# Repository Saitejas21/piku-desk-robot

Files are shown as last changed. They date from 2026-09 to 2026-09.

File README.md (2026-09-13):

<div align="center">

# Piku 🐰

**A tiny, sleepy bunny for your desk.**

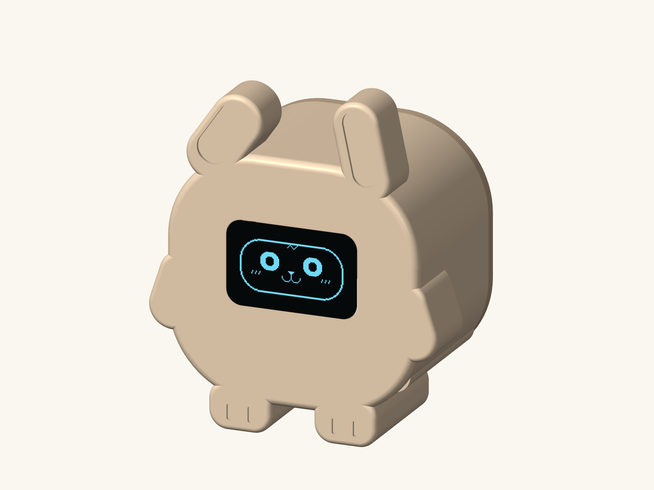
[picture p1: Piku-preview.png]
Piku, a cream bunny desk robot with a tilted ear, tiny paws, and a smiling full face on its OLED screen


USB powered · Touch reactive · About 6.4 cm tall

[Build guide](Piku-build-guide.docx) · [Download the project](https://github.com/Saitejas21/piku-desk-robot/archive/refs/heads/main.zip) · [Print files](cad) · [Push-in mounts](variants/slide-in) · [Otter variant](variants/otter) · [Cat variant](variants/cat)

<sub>CAD preview of the proposed build. The first physical build is still to be tested.</sub>

</div>

Piku is a small ESP32 hobby robot with one tilted ear, little paws, and a whole face on a monochrome OLED: eyes, nose, mouth, and cheeks. Its body stays still while its expressions do the talking.

The build uses **three small boards and two printed parts**. Start with one little win: get Piku's face blinking on the table. Put it in its bunny shell once the electronics work.

## Meet Piku

| What you do | What Piku does |
| --- | --- |
| Let it hang out | Blinks and glances left and right |
| Tap its head | Smiles |
| Double-tap within 450 ms | Shows heart eyes |
| Hold a touch for two seconds | Gives a shy wink |
| Leave it alone for a minute | Falls asleep |
| Touch it while sleeping | Wakes with a surprised face, then smiles |

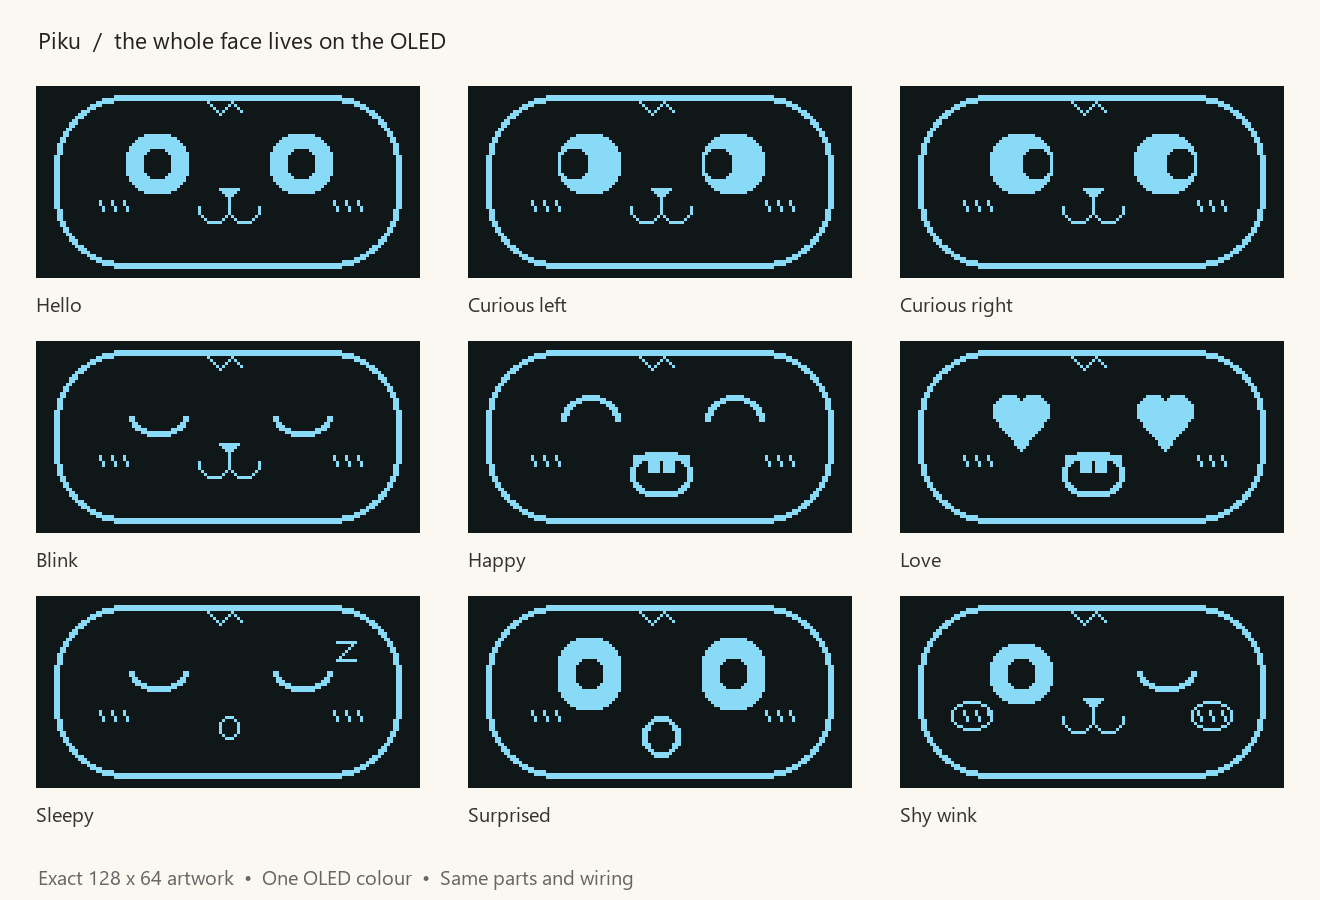
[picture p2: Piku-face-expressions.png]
Piku's nine OLED frames, including happy, love, sleepy, surprised, and a shy wink


These are the actual **128 × 64 pixel frames** included in the sketch. All features use the OLED's single pixel colour; the blue in the preview matches the linked display.

## Gather the little parts

Buy one of each board. **This shell and sketch are designed for the ESP32-C3 SuperMini and SSD1306 display below.**

| Part | What to look for | Buy |
| --- | --- | --- |
| ESP32-C3 SuperMini | HW-466AB, USB-C, with soldered headers | [Quartz Components](https://quartzcomponents.com/collections/nodemcu-esp/products/esp32-c3-super-mini-development-board-with-soldered-headers-hw-466ab) |
| 0.96″ OLED | SSD1306, 128 × 64, **four-pin I²C** | [Quartz Components](https://quartzcomponents.com/products/oled-display-0-96-inch-i2c-interface-4-pin-blue-ssd1306) |
| TTP223 touch sensor | Small **red 15 × 11 mm** board | [DNA Technology](https://www.dnatechindia.com/red-ttp-223-touch-switch-sensor-module-india.html) |

Also gather a USB-A to USB-C **data** cable, short female-to-female jumpers, thin hookup wire, two M2 × 6 mm self-tapping screws, thin double-sided tape, electrical tape, and small non-slip pads for the feet. You'll need access to a PLA printer or a printing service.

Borrow a soldering iron, solder, cutters, and a small screwdriver. Some headers and the shared power leads need soldering. Larger ESP32 boards and larger blue touch modules will not fit this shell. Servos are not part of this build.

The [four-page build guide](Piku-build-guide.docx) includes the shopping notes, budget, and assembly steps. Listing prices and stock can change.

## First win: a face on the table

1. Use **Code → Download ZIP** and extract the project.
2. Follow the [build guide](Piku-build-guide.docx) to wire the three boards on the table.
3. Install Arduino IDE, the ESP32 board package, and the display libraries. Open [`Piku.ino`](firmware/Piku/Piku.ino), keeping [`piku_faces.h`](firmware/Piku/piku_faces.h) beside it.
4. Upload, leave the touch pad alone for **two seconds**, then tap it to meet Piku.

<details>
<summary><strong>Wiring, Arduino settings, and quick fixes</strong></summary>

### Connect the boards

Unplug USB while wiring. Match the labels printed on each board.

| Module | Pin | ESP32-C3 connection |
| --- | --- | --- |
| OLED | VCC / VDD | 3V3 |
| OLED | GND | GND |
| OLED | SDA | GPIO4 |
| OLED | SCL / SCK | GPIO5 |
| TTP223 | VCC | 3V3 |
| TTP223 | GND | GND |
| TTP223 | OUT / I/O | GPIO3 |

Use short, soldered and insulated Y leads to share **3V3** and **GND** between the two modules. Both modules are powered from 3V3; neither connects to the ESP32's 5V pin. Set the TTP223 to **active-high momentary mode**, so its output is high only while touched.

### Upload Piku

1. Install [Arduino IDE](https://www.arduino.cc/en/software/) and the **esp32** board package by **Espressif Systems**. The [Espressif installation guide](https://docs.espressif.com/projects/arduino-esp32/en/latest/installing.html) covers setup.
2. In Library Manager, install **Adafruit SSD1306** and **Adafruit GFX Library**, including their dependencies.
3. Open `firmware/Piku/Piku.ino`. Select **ESP32C3 Dev Module**, **4 MB** flash, **USB CDC On Boot: Enabled**, and the connected port.
4. Upload using the data cable. Leave the touch pad alone for **two seconds** after power-up, then try a tap.

If the port is missing, try another data cable. To enter download mode, hold **BOOT**, tap **RESET**, release **BOOT**, and select the port again.

**Blank screen?** Check 3V3, GND, GPIO4, and GPIO5; the sketch tries addresses `0x3C` and `0x3D`. **Upside down?** Change `face.setRotation(0)` to `face.setRotation(2)`. **Touch stuck on?** Check momentary mode and move wires away from the sensing pad.

</details>

## Give Piku a home

Print **one of each** of these files:

| File | Orientation |
| --- | --- |
| [`piku_body.stl`](cad/piku_body.stl) | Face down, open back upward |
| [`piku_back.stl`](cad/piku_back.stl) | Exterior down, locating lip upward |

Use **PLA · 0.4 mm nozzle · 0.2 mm layers · 3 walls · 15% infill**, at **100% scale in millimetres**. The files already lie in their print orientations; supports should not be needed. The assembled shell is approximately **55 × 34 × 64 mm** including its ears and paws.

Measure your actual boards before printing. Align the lit OLED behind the opening, then mount the boards with tape as described in the guide. The touch sensor sits under the thin crown patch between the ears, toward the back. Close the lid with the two screws and tighten gently.

Cream or pastel PLA suits Piku. The inner ear recesses can be painted pink; leave the crown touch patch unpainted.

**Print only the body and back.** [`piku_assembly.step`](cad/piku_assembly.step) is an assembled CAD preview whose screen and face pixels are illustrative geometry.

## Optional: push-in module mounts

The [slide-in prototype](variants/slide-in) adds four releasable clips around the OLED PCB and two rails beneath the crown for the red touch sensor. Push the OLED in from the open back, then slide the touch board into place; the matching lid keeps the touch board from sliding out.

Its [instructions and print files](variants/slide-in/README.md) include small fit-test prints, STEP files, editable sources, and an interior preview. Use the prototype's PETG print guidance and matching body/lid pair. The holders use nominal board dimensions, and the snap fit still needs a physical test. The original build guide above covers the tape-mounted shell.

Thinking about a rechargeable Piku? The same page explains the [optional battery-power arrangement](variants/slide-in/README.md#could-piku-run-from-a-battery). A battery and charging board have not been selected or fitted yet.

## Piku the little otter 🦦

Prefer a little otter? The separate [otter variant](variants/otter) gives Piku a smooth seated body, small ears, resting paws, a cream belly and a low tail. It uses the same three boards and full OLED face, in a shell about **71 × 66 × 85 mm** (width × depth × height).

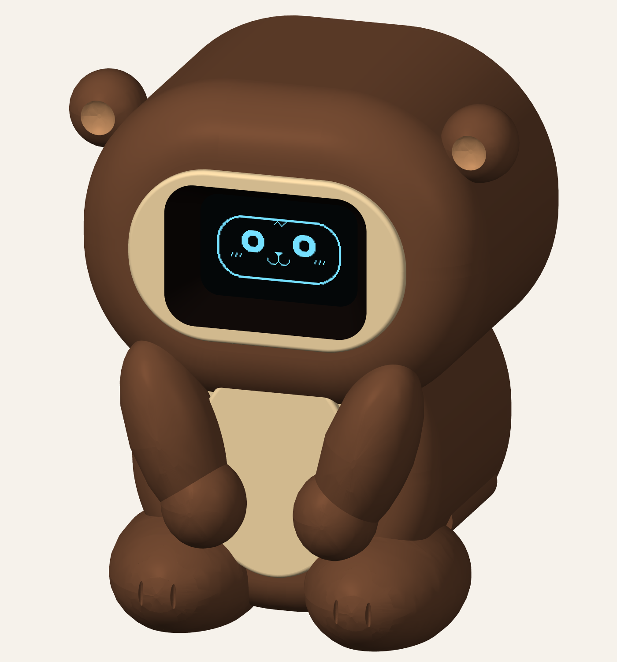
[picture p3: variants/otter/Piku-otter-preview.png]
Piku's seated otter variant with a full OLED face, little paws and a cream belly; actual CAD with suggested paint colours


Its [standalone guide and files](variants/otter/README.md) include clip-in or tape OLED mounting, a sliding touch-sensor holder, a removable C3 tray, a rear USB opening, fit-test prints, STEP/STL files, editable CAD and firmware. Print one body option, the matching rear cover and the tray. The bunny files and guide above remain unchanged.

The otter's modeled clearances and mesh checks pass, but it has not been physically printed or fitted. Start with the small fit tests and follow its own print guidance: **the otter body needs exterior supports**. Colours in the preview are suggested paint; battery and charging hardware have not been fitted.

## Piku the little cat 🐱

The [cat variant](variants/cat) gives Piku pointed ears, a seated body, short forelegs with tiny toes and a curled tail. Its refined proportions pair a smaller outer head with a slightly taller chest, while keeping the same three boards and whole OLED face. The shell is about **82.5 × 55.0 × 98.3 mm** (width × depth × height).

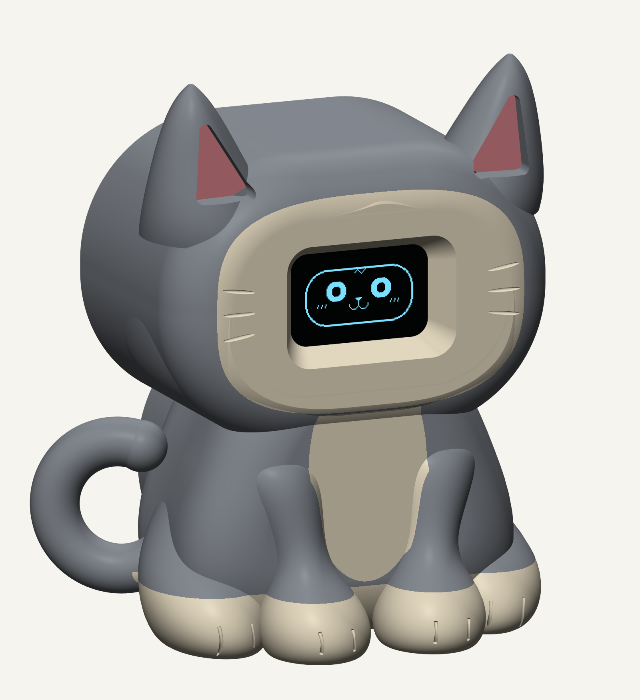
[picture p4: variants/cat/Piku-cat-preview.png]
Piku's refined cat variant, painted grey and cream with pink inner ears and a glowing cyan OLED face


Its [build guide and files](variants/cat/README.md) include clip-in or tape OLED mounting, a sliding touch holder, removable C3 tray, rear USB access, fit coupons, STEP/STL files, editable CAD and firmware. The [individual image](variants/cat/Piku-cat-preview.png) is a render of the actual refined CAD with suggested paint.

CAD mesh and nominal clearance checks pass; physical printing and fit are still untested. The cat body needs exterior supports. Follow its own print and assembly instructions, starting with the small fit tests.

## Tinker with Piku

- **Faces:** [`piku_faces.h`](firmware/Piku/piku_faces.h) holds the nine monochrome bitmaps. Hello looks straight ahead; curious pupils move toward the viewer's left or right inside fixed eye shapes. Edit [`tools/generate_faces.py`](tools/generate_faces.py) and run `python tools/generate_faces.py` with Pillow 10.1+ installed to regenerate the bitmaps, expression sheet, and CAD face data.
- **Behaviour:** [`Piku.ino`](firmware/Piku/Piku.ino) controls blinking, touch reactions, and the sleep timer.
- **Shell:** The [`cad` folder](cad) includes STEP files and editable [build123d](https://github.com/gumyr/build123d) Python sources. The assembly reads [`piku_face_pixels.json`](cad/piku_face_pixels.json) for its face preview.

## Build status

Piku is an **early hobby prototype**. The [CAD validation results](cad/validation.json) report valid single solids for both print parts, closed STL meshes with consistent winding, and no positive-volume overlap between the body and lid.

The shell has **not been physically printed or fitted**. Test the electronics on the table before closing the shell.

The browser links in `cad/preview-links.md` point to the original author's local CAD viewer. To inspect the model on your own computer, open the included STEP or STL files in a CAD viewer or slicer.

## License

Original Piku CAD and firmware are available under the [MIT license](LICENSE.txt). Third-party libraries and the document template retain their own licenses.

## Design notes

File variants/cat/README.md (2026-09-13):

# Piku the little cat 🐱

A seated chibi kitten with pointed ears, short forelegs, tiny toe creases and a curled tail. **The whole animated face lives on the OLED.**

Refined Piku cat with a grey coat, cream face surround and paws, pink inner ears and its full cyan OLED face switched on

**About 82.5 mm wide × 55.0 mm deep × 98.3 mm tall**, including ears and tail. This is the refined cat variant: a smaller outer head and slightly taller torso, using the same OLED, touch sensor and ESP32-C3 SuperMini. There are no servos.

[Print files](cad) · [Firmware](firmware/Piku) · [Download image](Piku-cat-preview.png) · [Design notes](design-notes.md) · [Back to Piku](../../README.md)

The image is a render of the actual CAD with suggested paint colours and the existing OLED pixels. Paint does not add separate parts. The shell has no physical eyes, nose, mouth or muzzle. Printing and real module fit still need testing.

Open the [OLED-on assembly](cad/cat_assembly.step), [OLED-off assembly](cad/cat_shell_review.step) or [open-back assembly](cad/cat_inside.step) in a STEP viewer. Assemblies are for inspection; print the individual parts listed below.

The [proportion checks](cad/proportion-check.json) record an **8.0% reduction in outer head-envelope volume** and a **6.4% increase in sculpted torso height** against the earlier cat. The free electronics cavity, display hardware and mounts, central touch crown, removable tray and rear cover are unchanged. The bunny, slide-in bunny and otter remain separate variants.

## The same little parts

| Part | Where it goes | Guide's shopping link |
| --- | --- | --- |
| ESP32-C3 SuperMini HW-466AB | On the removable lower tray, USB facing the back | [Quartz Components](https://quartzcomponents.com/collections/nodemcu-esp/products/esp32-c3-super-mini-development-board-with-soldered-headers-hw-466ab) |
| 0.96″ SSD1306 OLED, 128 × 64, four-pin I²C | Behind the face opening | [Quartz Components](https://quartzcomponents.com/products/oled-display-0-96-inch-i2c-interface-4-pin-blue-ssd1306) |
| Small red TTP223, 15 × 11 mm | Slides beneath the crown, between the ears | [DNA Technology](https://www.dnatechindia.com/red-ttp-223-touch-switch-sensor-module-india.html) |

Also gather a USB-C **data** cable, short jumper wires, thin hookup wire, insulating mounting tape, **four M2 × 6 mm self-tapping screws** and small non-slip pads. Optional small cable ties can hold the C3 on its tray. Keep them clear of its antenna, buttons, connector and components. Some headers and shared power leads may need soldering.

These are the same parts selected for the Piku guide. The model uses nominal board dimensions; measure the modules you receive before printing. Larger ESP32 boards, SPI displays and larger touch modules need different holders.

## What to print

Print **one body option, one rear cover and one C3 tray**. The ears, paws and tail are integral parts of the body. The rear cover, tray and fit-test prints are unchanged from the original cat revision.

| File | Use |
| --- | --- |
| [cat_body.stl](cad/cat_body.stl) | Four releasable OLED clips, touch rails and tray rails |
| [cat_body_tape.stl](cad/cat_body_tape.stl) | Alternative body with OLED corner supports and no OLED clips; use insulating tape |
| [cat_back.stl](cad/cat_back.stl) | Matching screwed cover, USB opening and fingers retaining the touch board and tray |
| [cat_c3_tray.stl](cad/cat_c3_tray.stl) | Removable tray with raised insulating-pad supports and optional tie slots |

**Try the small fit prints first:** the [OLED coupon](cad/cat_oled_fit_test.stl), [touch coupon](cad/cat_touch_fit_test.stl), and the actual C3 tray. Check clip grip, board clearances, the complete lit face, USB alignment and touch through the crown material.

For the clip version, start with **PETG · 0.4 mm nozzle · 0.2 mm layers · 3 walls · 15% infill**, at **100% scale in millimetres**. Use matching material and settings for coupons and final parts. The tape body can also be tried in PLA.

The individual STEP/STL files are already in print orientation. The body is face toward the bed, open back upward. **It needs supports beneath exterior features**, including recessed front surfaces, ears and the tail. Inspect the slicer preview and keep supports out of clip gaps and sliding channels where possible. The rear cover, tray and coupons sit flat. No slicer or physical print has been tested here.

Use a single filament colour to keep the sculpted outline visible. The ear recesses can be painted pink if desired, but the review views deliberately use no colour accents. All print STLs are single-material parts. Leave the thin crown sensing patch unpainted.

## Put the kitten together

1. **Get its face working on the table first.** Connect the three boards, upload the sketch and check touch reactions.
2. **Fit the OLED from the open back**, screen facing forward and header at the top. Align the lit face, then press only clear PCB corners to engage the tabs. Never press the glass or ribbon. If it binds, adjust the holder or use the tape body.
3. **Slide the red touch board forward into the crown rails.** Its long 15 mm side runs front-to-back. The sensing pad faces the crown, components face inside, and the header stays toward the rear.
4. **Tape the C3 onto the raised tray pads with insulating tape.** The nominal layout allows 0.4 mm mounting pads and 2.2 mm downward solder tails. Check your actual pins and header orientation. Slide the loaded tray into the lower rails with USB facing the opening.
5. **Wire and route the short leads in the free side space.** Keep wires clear of the touch patch, rear rim and screw bosses. Check that the USB plug enters without forcing the board.
6. **Attach the back with four screws**, tightened gently. Its fingers retain the touch board and C3 tray. For servicing, remove the cover, disconnect the required leads and slide the parts out. Remove the touch board before releasing the OLED tabs.

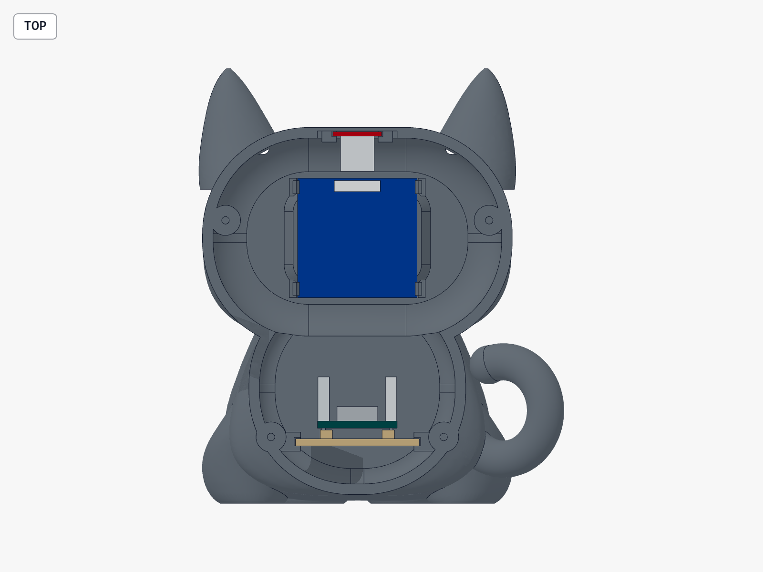
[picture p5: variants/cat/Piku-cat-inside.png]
Open-back layout showing the OLED, crown touch board and lower C3 tray


The [closed assembly](cad/cat_assembly.step) and [interior assembly](cad/cat_inside.step) show the nominal electronics and reserved connector/header space. **Do not print either assembly.** The coloured board solids are approximate fit envelopes, not additional parts or exact purchased-board models.

## Wiring and the first upload

Unplug USB while wiring and follow the labels printed on your boards.

| Connection | C3 pin |
| --- | --- |
| OLED VCC and touch VCC | 3V3, shared through an insulated Y lead |
| OLED GND and touch GND | GND, shared through an insulated Y lead |
| OLED SDA | GPIO4 |
| OLED SCL / SCK | GPIO5 |
| Touch OUT / I/O | GPIO3 |

Use active-high momentary mode on the touch board. In Arduino IDE, install the **esp32** board package by Espressif, **Adafruit SSD1306** and **Adafruit GFX Library**, including dependencies. Open [Piku.ino](firmware/Piku/Piku.ino) with [piku_faces.h](firmware/Piku/piku_faces.h) beside it. Choose **ESP32C3 Dev Module**, **4 MB** flash and **USB CDC On Boot: Enabled**, then upload using the data cable.

Leave the crown alone for two seconds after power-up, then tap it. Piku blinks and glances when idle, smiles on a tap, shows hearts on a double-tap, winks on a hold and sleeps after a quiet minute. Hello looks straight ahead; curious pupils move left or right. The [nine face frames](Piku-face-expressions.png) and firmware are unchanged from the existing Piku kit. Firmware has not been compiled or run on hardware here.

## Fit notes and editable CAD

| Interface | Nominal model assumption |
| --- | --- |
| OLED PCB | 27 × 27 × 1.2 mm; glass position and clear corner margins must be checked |
| Touch PCB | 11 × 15 × 1.0 mm; 1.3 mm rail slot |
| C3 PCB | 18 × 22.5 × 1.6 mm; headers and USB connector approximated |
| OLED clips | 0.25 mm side/axial allowances and 0.4 mm catch overlap |
| Crown | 0.8 mm central sensing wall; 0.15 mm nominal pad gap |
| Tray rails / lid lip | 0.3 mm nominal clearance |
| Rear USB opening | 16 × 14 mm; checked against a nominal 13 × 6 mm plug body |

The [validation report](cad/validation.json) records valid single print solids, closed and consistently wound meshes, nominal component clearances, wire corridors, insertion sweeps and selected display viewing angles. Flexible clip movement, real board fit, touch response and physical stability still need testing. Use the coupons; don't scale the entire cat to fix one holder.

Editable build123d Python sources sit beside their STEP files. Main parameters are in [cat_common.py](cad/cat_common.py). Raw coordinates use X for width, Y for standing height and +Z from front to back; generators transform each printable part onto the bed. The rear mating datum and screw centres are shared parameters. The sources were generated with build123d 0.11.1. Run [validate_cat.py](tools/validate_cat.py) with build123d after regenerating changed geometry. The [face generator](tools/generate_faces.py) uses Pillow 10.1+.

This version is **USB powered**. The validation includes an empty 24 × 20 × 6 mm envelope in the belly, but no battery, charger or battery mounting system has been selected or fitted.

The [CAD renderer](tools/render_comparison.py) recreates the painted preview from the actual model. Run `python tools/render_comparison.py --single` with build123d and VTK installed. Run it without flags to regenerate the front, side and painted proportion comparisons from the earlier source snapshot in `baseline/cad/`. The snapshots use build123d 0.11.1 and VTK 9.6.2.

Original Piku CAD and firmware are under the [MIT license](LICENSE.txt).

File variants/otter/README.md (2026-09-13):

# Piku the little otter

A smooth, seated otter for the same tiny Piku electronics. Big round head, small ears, paws resting over a cream belly, little feet and a low tail. Its **whole face still lives on the OLED**.

Piku otter — actual CAD with suggested paint colours

**About 71 mm wide × 66 mm deep × 85 mm tall.** The main closed body is about 51 mm deep; the tail adds the rest. Brown filament with a cream-painted muzzle surround and belly gives the reference's colour pattern. The preview shows suggested paint on the actual CAD geometry, not a knitted texture or a photograph of a built robot.

This is a separate otter variant. The [original bunny](../../README.md) and its [optional push-in mounts](../slide-in/README.md) remain available.

[Print files](cad) · [Firmware](firmware/Piku) · [Model previews](cad/preview-links.md)

## Same three little boards

| Part | Inside the otter | Buy the guide's part |
| --- | --- | --- |
| ESP32-C3 SuperMini HW-466AB | On a removable tray in the lower body, USB facing the rear | [Quartz Components](https://quartzcomponents.com/collections/nodemcu-esp/products/esp32-c3-super-mini-development-board-with-soldered-headers-hw-466ab) |
| 0.96″ SSD1306, 128 × 64, four-pin I²C OLED | Behind the cream face surround, with clips or tape pads | [Quartz Components](https://quartzcomponents.com/products/oled-display-0-96-inch-i2c-interface-4-pin-blue-ssd1306) |
| Small red TTP223 touch module, 15 × 11 mm | In sliding rails under the thin crown | [DNA Technology](https://www.dnatechindia.com/red-ttp-223-touch-switch-sensor-module-india.html) |

Also use a USB-C **data** cable, short jumper wires, thin insulating mounting tape, four M2 × 6 mm self-tapping screws and small non-slip pads. Optional small cable ties can secure the C3 on its tray; route them clear of its buttons, antenna, USB connector and components. There are no servos.

## Choose the OLED holder

- **Push-in clips:** use [otter_body.stl](cad/otter_body.stl). The four tabs catch the exposed PCB corner edges. Release the tabs gently to remove the display.
- **Tape option:** use [otter_body_tape.stl](cad/otter_body_tape.stl). It has the same corner supports and front surround, with the OLED clips omitted. Secure only clear PCB margins using thin insulating mounting tape.

Both bodies use the same touch rails, C3 tray and rear cover. **Print one body option, one [back](cad/otter_back.stl), and one [C3 tray](cad/otter_c3_tray.stl).** The tail and paintable accents are already part of the body, so they need no separate printing or assembly.

## Print the small fit tests first

| File | Check |
| --- | --- |
| [OLED test](cad/otter_oled_fit_test.stl) | PCB thickness, corner clearance, clip grip and visibility of the complete lit face |
| [Touch test](cad/otter_touch_fit_test.stl) | Sliding fit and touch response through the crown wall |
| [C3 tray](cad/otter_c3_tray.stl) | Board placement, pin-end clearance and USB alignment; this is the actual removable tray |

Use **PETG, a 0.4 mm nozzle, 0.2 mm layers, 3 walls and 15% infill**, at **100% scale in millimetres**, as starting settings for the clip version. Use the same material and settings for the fit tests and final body. The tape body can also be tried in PLA. These are starting settings; the model has not been sliced or printed on your printer.

The STL and individual part STEP files are already in print orientation. The main body sits **face toward the bed, back opening upward**. Its rounded face, paws and belly have different front depths, so **it needs supports under exterior surfaces**. Inspect the slicer preview and keep supports out of the clip gaps and sensor channels where possible. The rear cover, tray and fit tests sit flat. Check the small rail ledges and latch ramps in the coupons before committing to the whole body.

Paint the raised muzzle surround and belly cream if desired. A dark inside edge around the face opening hides reflections. Leave the thin crown sensing patch unpainted. The body, back and tray STLs are single-material parts; the colour preview is a painting suggestion.

## Put the little otter together

1. **Test the electronics on the table first.** Upload the included Piku sketch and check the full face and touch reactions.
2. **Fit the OLED from the open back**, display facing forward and header at its upper edge. Align the lit face. Press only clear PCB corners when fitting clips, never the glass or ribbon. If it binds, stop and adjust the holder dimensions or choose the tape body.
3. **Slide the red touch board into the crown rails** from the rear. Its long 15 mm direction runs front-to-back; the sensing pad faces the crown and the header stays at the rear. Keep its component side facing the interior.
4. **Attach the C3 to its tray with insulating tape on the raised pads.** The nominal model allows a 0.4 mm mounting pad and 2.2 mm downward solder tails. Check your actual header orientation and pin lengths. Slide the loaded tray into the lower rails, checking the USB connector lines up with the rear opening. The rails grip the plastic tray; the PCB stays on its adjustable mounting pads.
5. **Connect the short leads and tuck them into the free side space.** Keep wiring away from the thin touch patch and out of the rear cover's mating rim. Verify the USB plug can enter freely.
6. **Fit the back around the low tail and fasten the four screws gently.** Its fingers retain both the touch board and the C3 tray. To service Piku, remove the cover, disconnect the necessary leads, then withdraw the tray or touch board. Remove the touch board before releasing the OLED tabs.

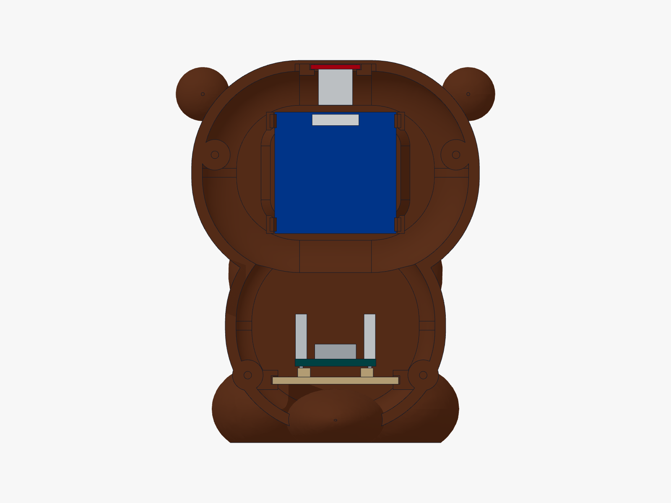
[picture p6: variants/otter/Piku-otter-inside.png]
Open-back view: OLED, touch board and C3 tray


The blue/red/teal solids in the [interior STEP](cad/otter_inside.step) are nominal board envelopes. Grey boxes reserve room for headers, connectors and components; they are not exact purchased-part models or additional parts to buy. [The closed assembly](cad/otter_assembly.step) shows the standing character and its actual firmware face pixels. **Do not print either assembly.**

## Wire and upload

Unplug USB while wiring. Match the labels printed on the boards.

| Connection | C3 pin |
| --- | --- |
| OLED VCC and touch VCC | 3V3, shared through an insulated Y lead |
| OLED GND and touch GND | GND, shared through an insulated Y lead |
| OLED SDA | GPIO4 |
| OLED SCL / SCK | GPIO5 |
| Touch OUT / I/O | GPIO3 |

Use active-high momentary mode on the touch board. Open [firmware/Piku/Piku.ino](firmware/Piku/Piku.ino), keeping [piku_faces.h](firmware/Piku/piku_faces.h) beside it. Install the ESP32 Arduino board package plus Adafruit SSD1306 and Adafruit GFX Library. Choose **ESP32C3 Dev Module**, **4 MB** flash and **USB CDC On Boot: Enabled**. Upload with the data cable. Leave the crown alone for two seconds after power-up, then tap it.

The included firmware and nine [face expressions](Piku-face-expressions.png) are unchanged from Piku: idle blink/glances, tap to smile, double-tap for hearts, hold for a shy wink, and sleep after a quiet minute. It has not been compiled or run on hardware here.

## Fit assumptions and checks

| Interface | Model assumption |
| --- | --- |
| OLED PCB | 27 × 27 × 1.2 mm; glass and active-area position nominal |
| Touch PCB | 11 × 15 × 1.0 mm; 1.3 mm rail slot |
| C3 PCB | 18 × 22.5 × 1.6 mm; USB and header geometry nominal |
| OLED clips | 0.25 mm side allowance, 0.25 mm axial allowance, 0.4 mm catch overlap |
| Crown sensing wall | 0.8 mm at centre; nominal sensor gap 0.15 mm |
| C3 tray rails / lid lip | 0.3 mm nominal clearance |
| Rear cable opening | 16 × 14 mm; checked against a nominal 13 × 6 mm plug body |

The [OLED seller](https://quartzcomponents.com/products/oled-display-0-96-inch-i2c-interface-4-pin-blue-ssd1306) gives approximate 27 × 27 × 4.1 mm overall module dimensions, and the [touch seller](https://www.dnatechindia.com/red-ttp-223-touch-switch-sensor-module-india.html) lists 15 × 11 mm. The PCB thicknesses, clear corner margins, C3 footprint and detailed connector geometry above remain fit assumptions. Measure received modules and use the coupons; don't scale the whole otter to fix one holder.

The [validation report](cad/validation.json) records print-solid and mesh checks, assembled clearances, insertion paths and selected OLED viewing angles. It also checks space reserved for wiring. The flexible click action is not simulated, and physical print, fit and touch performance still need testing. Run [tools/validate_otter.py](tools/validate_otter.py) with build123d to repeat the geometric checks after changing dimensions. Editable sources are beside the STEP files; key dimensions live in [otter_common.py](cad/otter_common.py).

## Battery later

This kit is USB powered. The layout includes a checked **24 × 20 × 6 mm spare envelope** in the belly, clear of the modeled boards and reserved wire lanes. It is **not a selected or mounted battery**, and it does not establish space for a complete charging system. A rechargeable version still needs a chosen protected cell, matching charger/power circuit, mounting and a connector layout before it can be called fitted.

Original Piku CAD and firmware are under the [MIT license](LICENSE.txt). The bunny kits are separate and unchanged.

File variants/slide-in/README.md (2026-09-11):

# Piku — push-in OLED, slide-in touch sensor

This is a separate prototype shell revision for the parts in [Piku's build guide](../../Piku-build-guide.docx). The bunny outline, face opening, rear cable opening and two lid screws stay the same. The original hobby kit remains the simpler tape-mount version.

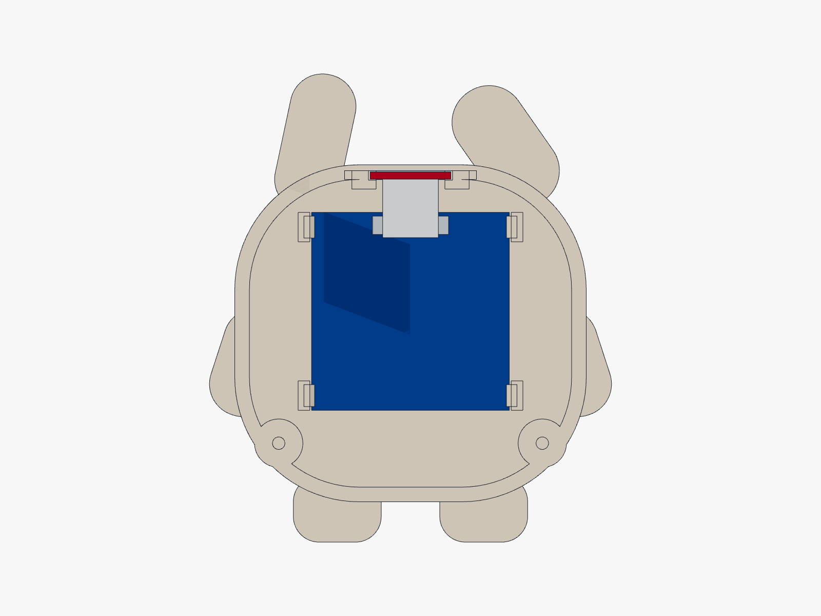
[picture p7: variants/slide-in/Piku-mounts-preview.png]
Rear view of Piku with the blue OLED PCB held by four clips and the red touch board in its crown rails


[See the empty holders](Piku-empty-mounts.png) · [Back to Piku](../../README.md)

## How the modules go in

1. **OLED first:** with the back open, lower the display face-first onto its four corner supports. The four ramped tabs are designed to deflect and catch the PCB edges. Apply light pressure only at clear PCB corners; keep pressure off the glass and ribbon. If it binds, stop and adjust the holder parameters. Headers face into the body, at the top of the display.
2. **Touch sensor next:** slide the small red board forward from the rear, sensor side against the crown and components facing the interior. Its long 15 mm dimension runs front-to-back. Two rails capture its outside PCB margins; the three-pin header stays toward the back.
3. **Close the matching lid:** its two small fingers keep the touch board from sliding out. This sensor holder uses the screwed lid as its end stop, so there is no tiny sensor latch to bend.

To remove the OLED, remove the touch board first, ease the OLED tabs outward and lift the PCB a little at a time. Do not pull on the screen or wires. Wire the modules using the [original guide](../../Piku-build-guide.docx) after testing their fit.

## Print the little tests first

| Print | Purpose |
| --- | --- |
| [OLED fit test](cad/piku_oled_fit_test.stl) | Same four supports, clips and viewing aperture; test PCB fit and screen alignment. |
| [Touch fit test](cad/piku_touch_fit_test.stl) | Same rail slot, front stop and crown wall; test sliding fit and touch response. |
| [New body](cad/piku_body.stl) | Full bunny shell with both holders. |
| [Matching back](cad/piku_back.stl) | Lid with the touch-board retaining fingers. |

Use the **same PETG and printer settings** for coupons and body: 0.4 mm nozzle, 0.2 mm layers, 3 walls, 100% scale in millimetres. All STL files are already in their print orientation. Keep support material out of the rail channels and clip gaps; inspect and clean these after printing. The small clip overhangs and rail ledges need a coupon check on your printer. PLA snap durability has not been established here.

The OLED clips are designed for a click as they catch the board, but their holding force and repeated flexing have **not been physically tested**. Successful CAD checks do not establish a working snap fit.

## Dimensions to confirm

| Interface | Model value | Basis |
| --- | --- | --- |
| OLED PCB footprint | 27 × 27 mm | Approximate dimensions from the [selected OLED listing](https://quartzcomponents.com/products/oled-display-0-96-inch-i2c-interface-4-pin-blue-ssd1306). |
| OLED PCB thickness | 1.2 mm | Assumed; measure the bare PCB, excluding glass/components. |
| OLED glass envelope | 26.5 × 19.4 mm; 2.9 mm projection | Assumed for clearance; verify glass edges, active-area offset and exposed corner margins. |
| OLED side / axial allowance | 0.25 / 0.25 mm | Starting print tolerances. |
| OLED catch overlap | 0.4 mm | Each clip overlaps the PCB edge. |
| Touch PCB footprint | 11 × 15 mm | [Selected red TTP223 listing](https://www.dnatechindia.com/red-ttp-223-touch-switch-sensor-module-india.html). |
| Touch PCB thickness / slot | 1.0 / 1.3 mm | Thickness assumed; 0.3 mm total slot allowance. |
| Crown wall at centre | 0.8 mm | Existing thin sensing patch; nominal board-to-roof gap 0.15 mm. |

The module sellers do not specify all the dimensions needed for clips. Check component and solder-joint clearance at the contact margins as well as board thickness. The display sits recessed in this revision to make room for the clip flex span. Check that the complete lit face is visible through the test aperture before printing the body. Parameters and nominal envelopes are in [piku_mounts.py](cad/piku_mounts.py); do not scale the entire shell to compensate for one interface.

## Could Piku run from a battery?

Yes. A suitable architecture for the existing C3 SuperMini is:

**Protected single-cell LiPo → charger with power-path/load sharing + regulated 5 V output → C3 power input.**

The charger’s USB input would sit behind the existing **16 × 14 mm rear opening**, if the selected board and plug fit there. The C3's USB-C port is for power/programming; this design does not add battery charging to that port. Its [listing specifies 5 V USB power](https://quartzcomponents.com/collections/nodemcu-esp/products/esp32-c3-super-mini-development-board-with-soldered-headers-hw-466ab), and does not document a battery charger.

Choose the protected cell and charger together: the charge current must stay within the cell's specified limit. Use a regulator with adequate peak-current headroom; an automatic-shutoff power-bank module must also stay awake at Piku's idle current. If Piku is to run while charging, choose a board that explicitly supports power-path/load sharing. [Adafruit's charger/boost explanation](https://learn.adafruit.com/adafruit-powerboost-1000c-load-share-usb-charge-boost/overview) shows this architecture; that particular board and its charge current have not been selected for Piku.

Do not connect a raw LiPo to the 3V3 pin: a full conventional cell is 4.2 V, above the C3's 3.6 V maximum. See the [Espressif electrical ratings](https://www.espressif.com/sites/default/files/documentation/esp32-c3_datasheet_en.pdf). Disconnect the battery system's 5 V output before using the C3 USB port for programming unless proper reverse-current isolation has been verified. A charger’s load sharing alone does not establish isolation between those two C3 power sources.

There is **no selected battery, charging board, battery holder or power wiring in this revision**. Their combined fit, connector access and charge-current settings still depend on the actual parts. Keep a pouch cell in a smooth insulated holder with space specified by its maker; do not squeeze it between boards or against screw tips. Battery runtime has not been measured.

## What was checked

The [validation report](cad/validation.json) records valid single solids, closed consistently oriented STL meshes, zero body/lid overlap, zero interference with the modeled seated boards, and clear straight insertion paths. OLED insertion was checked against rigid material with its intentionally flexible clips excluded; the clip motion itself was not simulated. The touch insertion path was also checked with the OLED already installed. The nominal component/header boxes help catch layout conflicts; they are not exact purchased-board CAD.

Open [the interior assembly](cad/piku_mount_preview.step) to inspect the blue OLED and red touch board envelopes. It is a review assembly, not a print file. The C3, battery and wiring are not modeled. Sources and STEP files are beside every printable part. Download the STEP or STL files and open them in your CAD viewer or slicer to inspect them locally.

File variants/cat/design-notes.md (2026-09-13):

# Cat shape and proportions

Piku keeps a soft seated-cat silhouette: broad pointed ears, cheeks around the OLED, shaped forelegs that widen into planted paws, folded haunches, shallow toe creases and a curled side tail. Grey, cream and pink are paint suggestions, not multi-material STL parts.

## Refined proportions

| Measurement | Earlier cat | Published cat |
| --- | --- | --- |
| Closed outer head envelope, excluding ears | 133.22 cm³ | 122.55 cm³, **8.0% smaller** |
| Maximum head width, excluding ears | 76.66 mm | 70.00 mm |
| Sculpted torso-envelope height | 50.07 mm | 53.26 mm, **6.4% taller** |
| Overall height with ears | 98.30 mm | 98.30 mm |
| Usable electronics cavity | 145.72 cm³ | 145.72 cm³ |

Head volume is measured before cavity subtraction. Only the cosmetic outer form changes; the OLED itself is not scaled. The torso measurement describes its sculpted envelope, while visible chest height also depends on overlap with the head.

The ears, forelegs/paws, haunches and tail retain their previous geometry. The cream face surround is slightly smaller and the shallow whisker details follow it. The earlier CAD source snapshot in `baseline/cad/` supports reproducible comparison renders.

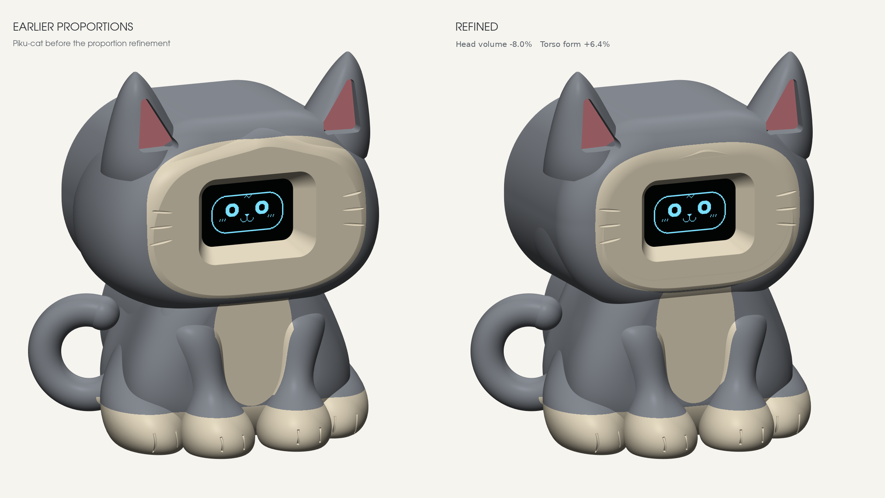
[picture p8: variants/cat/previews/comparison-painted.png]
Earlier and refined proportions, painted, with OLED on


[Front, OLED off](previews/comparison-front.png) · [Three-quarter, OLED off](previews/comparison-three-quarter.png) · [Side, OLED off](previews/comparison-side.png)

## Fit and validation

The [proportion-study report](cad/proportion-check.json) is the validation snapshot made before publication. It records zero symmetric difference between the old and refined free cavities and between their central touch-crown patches, unchanged hardware/limb helpers, and unchanged rear cover, C3 tray and fit-test parts. Its original-file hash check refers to the preserved source workspace at the time of that comparison.

The [geometry validation](cad/validation.json) records valid single print solids, closed and consistently wound STL meshes, no nominal component interference, clear USB and wiring paths, module insertion sweeps and selected OLED viewing angles. These CAD checks do not establish physical clip action, print support quality, touch response or real board fit. Follow the build guide and print the fit coupons first.

## Form references

[Knitted Cat by Smoggy3D](https://makerworld.com/en/models/1085872-knitted-cat) informed the compact seated proportions and integrated pointed ears. [CaT-Rex by DjangoUnnamed](https://makerworld.com/en/models/1706146-cat-rex), a kitten in a dinosaur costume, informed the short forelegs, broad paws and tucked hips. Only general cat form cues were studied; no reference meshes were downloaded, copied or included. Piku uses smooth surfaces and keeps its entire face on the OLED.

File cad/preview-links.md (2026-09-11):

# Piku CAD viewer

These links use the local CAD Explorer on the computer where this kit was made. Open the STEP or STL files in your own CAD viewer on another computer.

- [piku_assembly.step](http://127.0.0.1:4178/?file=outputs/Piku/cad/piku_assembly.step)
- [piku_body.step](http://127.0.0.1:4178/?file=outputs/Piku/cad/piku_body.step)
- [piku_back.step](http://127.0.0.1:4178/?file=outputs/Piku/cad/piku_back.step)
- [piku_body.stl](http://127.0.0.1:4178/?file=outputs/Piku/cad/piku_body.stl)
- [piku_back.stl](http://127.0.0.1:4178/?file=outputs/Piku/cad/piku_back.stl)

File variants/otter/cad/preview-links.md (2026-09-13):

# Piku otter — model previews

Download the STEP or STL files below and open them in a CAD viewer or slicer. The assembly and interior models are for inspection; print the individual parts listed in the [variant guide](../README.md).

- [Colour preview of the actual CAD](../Piku-otter-preview.png)
- [Open-back interior preview](../Piku-otter-inside.png)

- [otter_assembly.step](otter_assembly.step)
- [otter_back.step](otter_back.step)
- [otter_back.stl](otter_back.stl)
- [otter_body.step](otter_body.step)
- [otter_body.stl](otter_body.stl)
- [otter_body_tape.step](otter_body_tape.step)
- [otter_body_tape.stl](otter_body_tape.stl)
- [otter_c3_tray.step](otter_c3_tray.step)
- [otter_c3_tray.stl](otter_c3_tray.stl)
- [otter_inside.step](otter_inside.step)
- [otter_oled_fit_test.step](otter_oled_fit_test.step)
- [otter_oled_fit_test.stl](otter_oled_fit_test.stl)
- [otter_touch_fit_test.step](otter_touch_fit_test.step)
- [otter_touch_fit_test.stl](otter_touch_fit_test.stl)

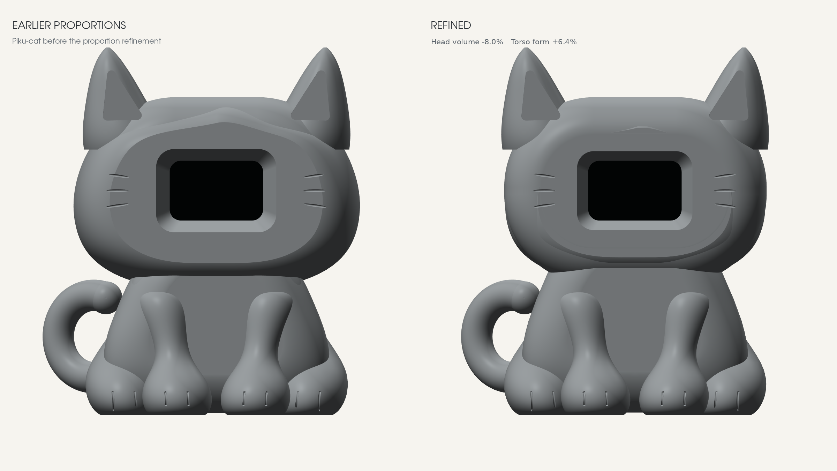
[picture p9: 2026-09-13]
variants/cat/previews/comparison-front.png

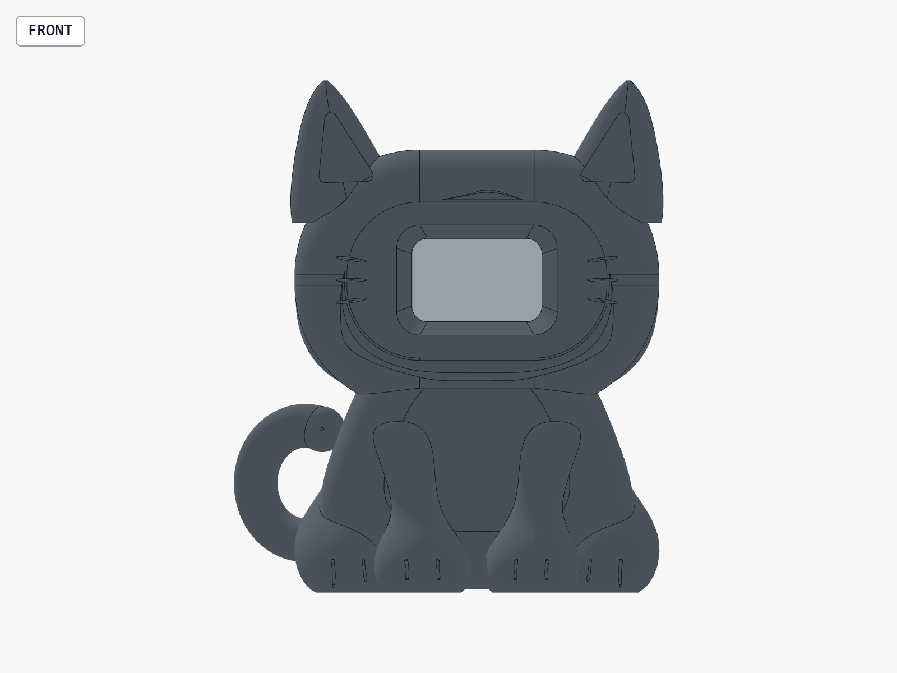
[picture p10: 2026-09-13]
variants/cat/previews/proposed-cad-front.png

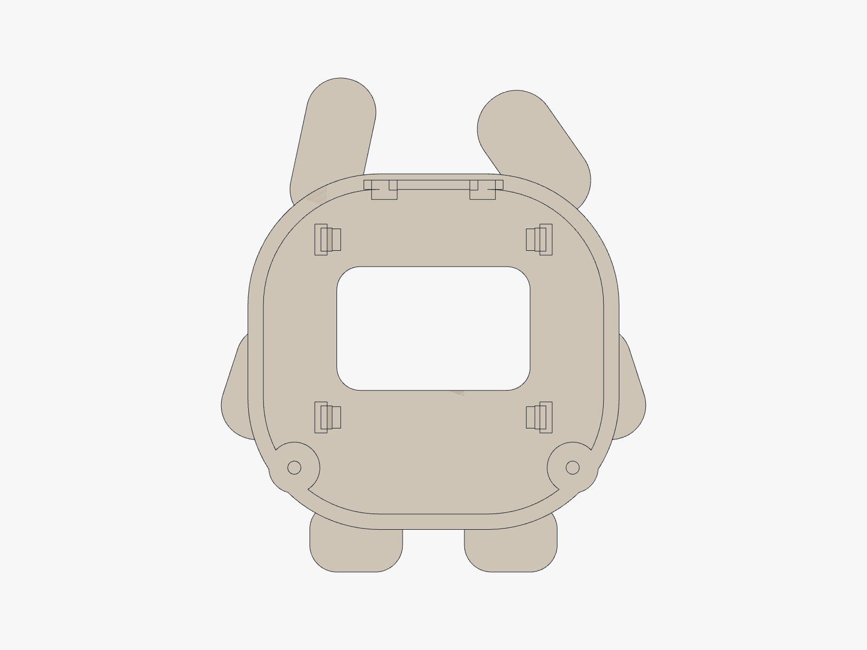
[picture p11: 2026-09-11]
variants/slide-in/Piku-empty-mounts.png

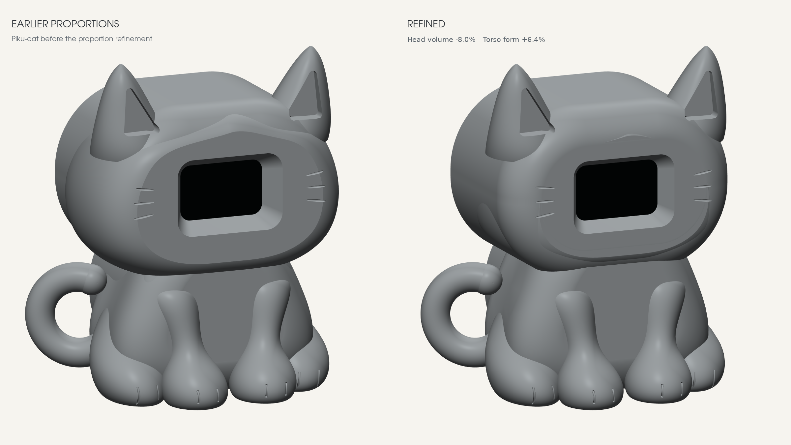
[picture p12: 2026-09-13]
variants/cat/previews/comparison-three-quarter.png

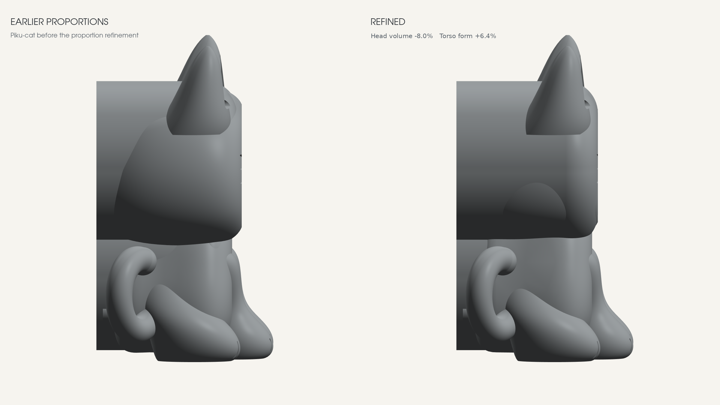
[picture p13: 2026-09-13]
variants/cat/previews/comparison-side.png

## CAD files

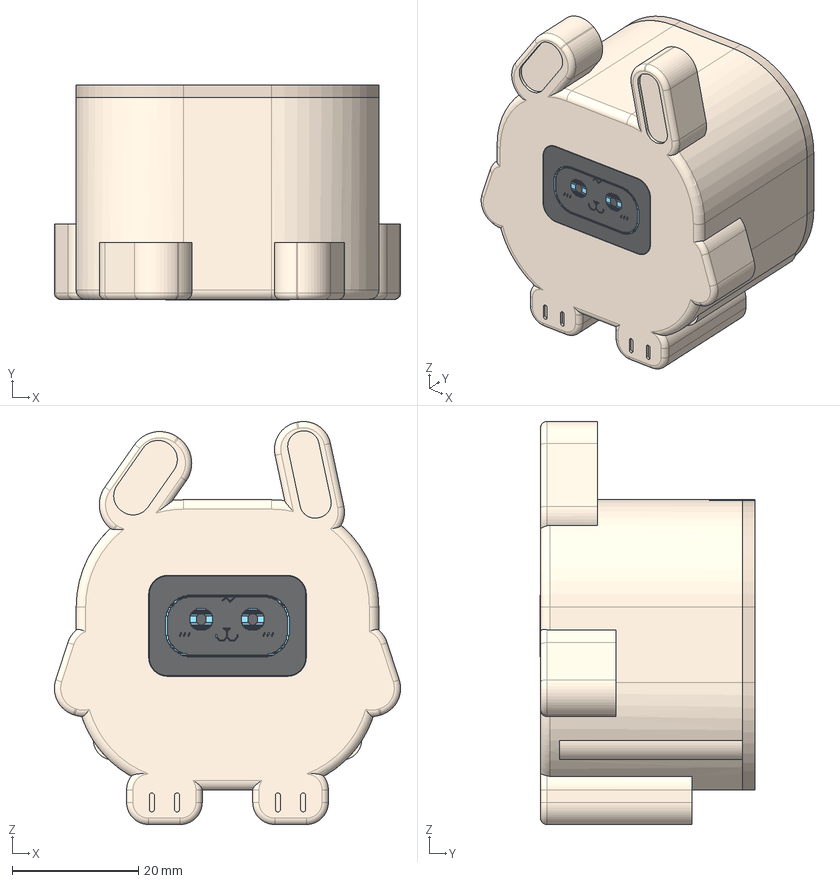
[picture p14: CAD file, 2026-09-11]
cad/piku_assembly.step
54.9 x 34.1 x 63.9 mm

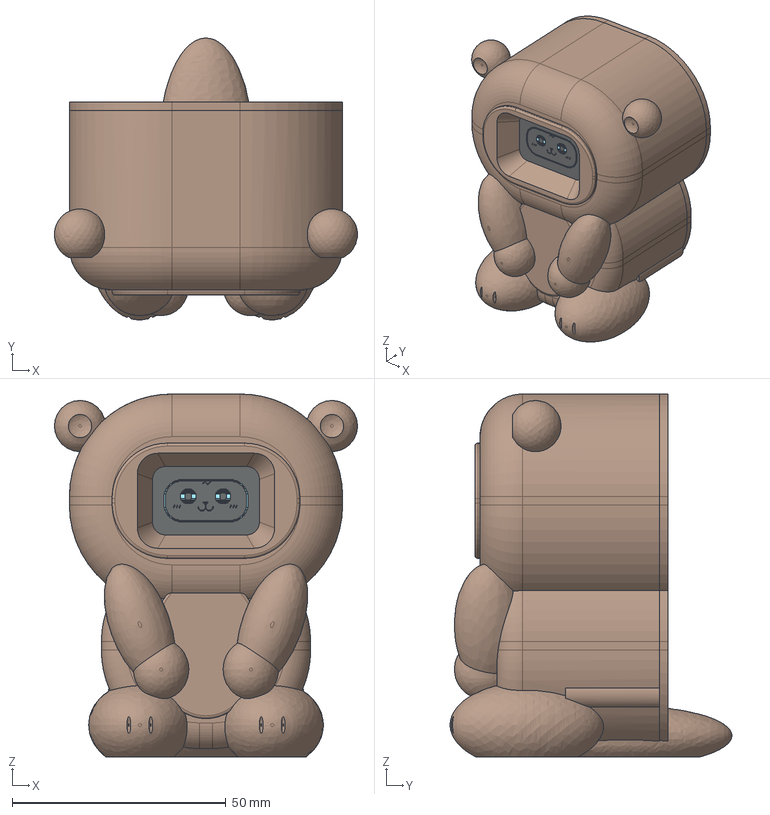
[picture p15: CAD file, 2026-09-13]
variants/otter/cad/otter_assembly.step
71.0 x 66.0 x 85.0 mm

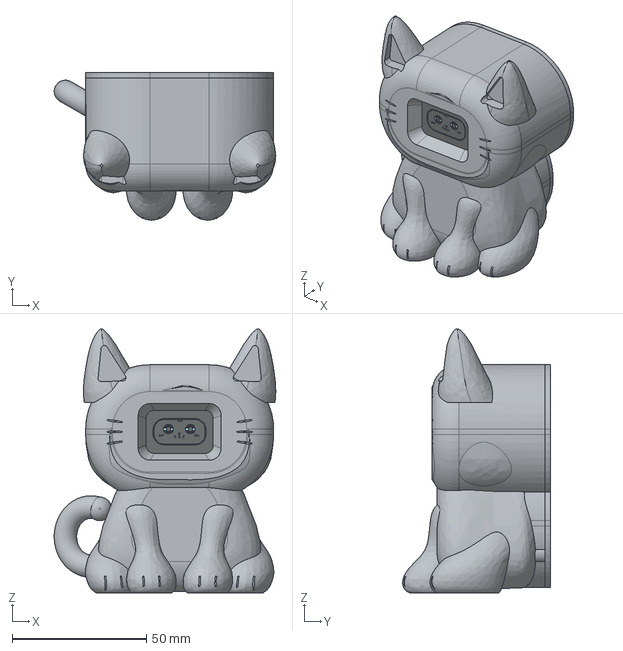
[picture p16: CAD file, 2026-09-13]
variants/cat/cad/cat_assembly.step
82.5 x 55.0 x 98.3 mm

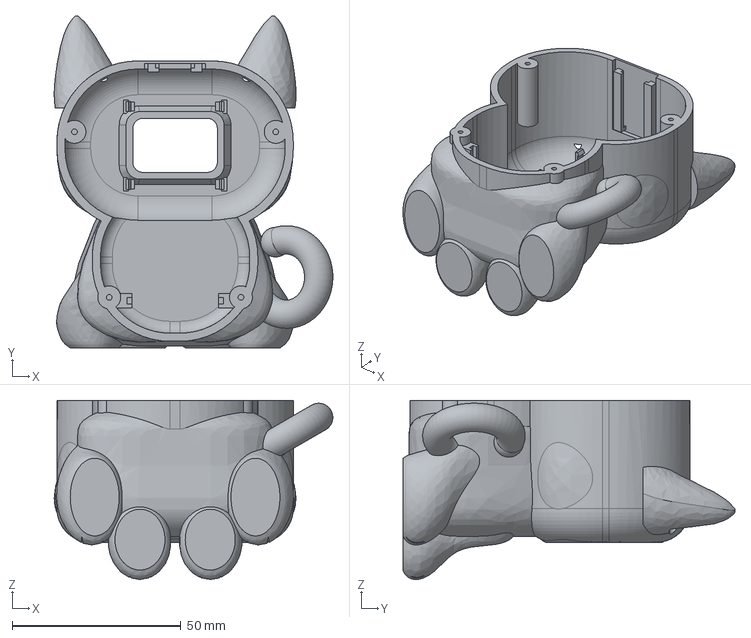
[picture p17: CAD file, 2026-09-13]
variants/cat/cad/cat_body.step
82.5 x 98.3 x 53.0 mm

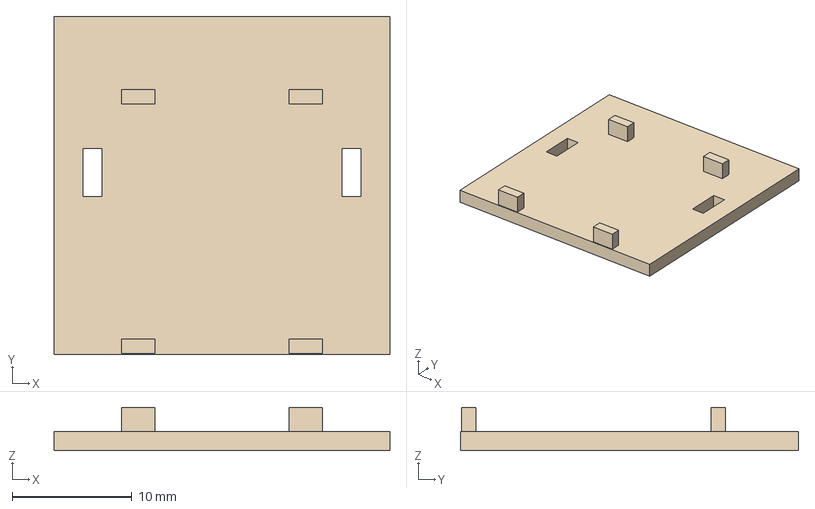
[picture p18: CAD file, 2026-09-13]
variants/otter/cad/otter_c3_tray.step
28.0 x 28.2 x 3.60 mm

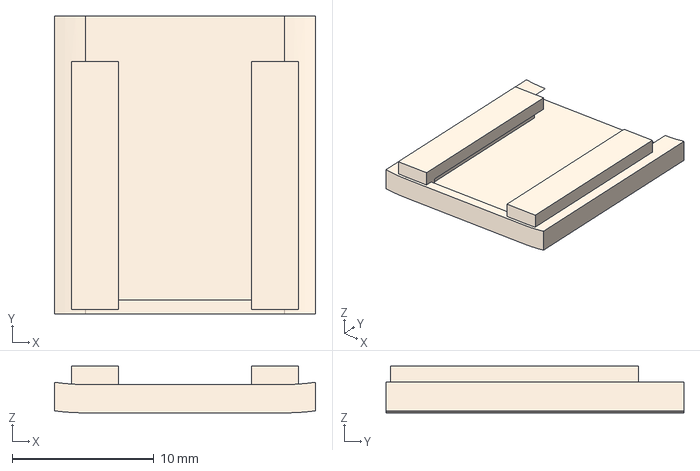
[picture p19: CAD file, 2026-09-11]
variants/slide-in/cad/piku_touch_fit_test.step
18.4 x 21.0 x 3.30 mm

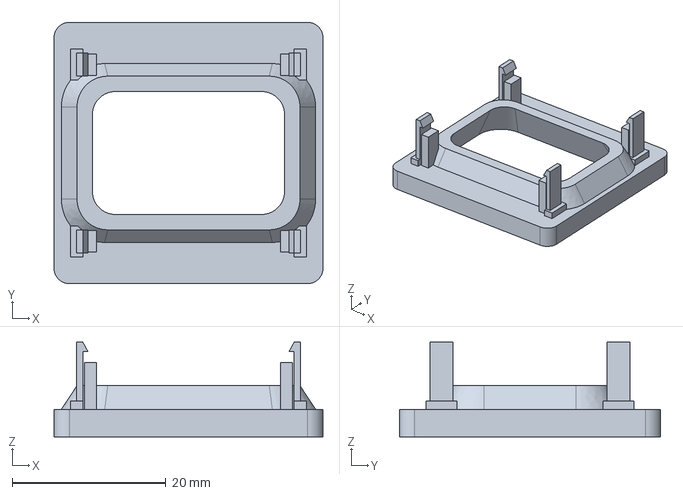
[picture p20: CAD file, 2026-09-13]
variants/cat/cad/cat_oled_fit_test.step
35.0 x 34.0 x 12.3 mm

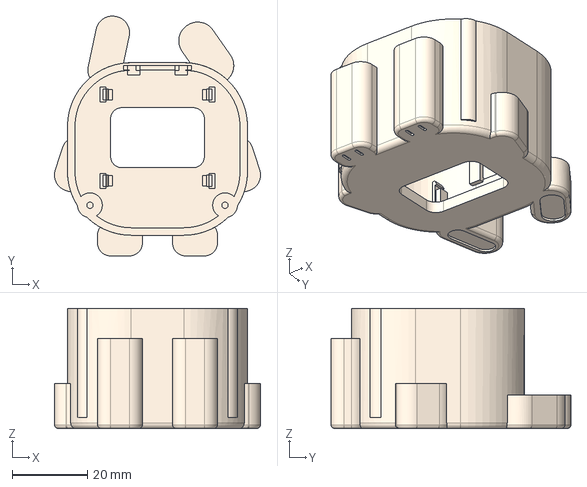
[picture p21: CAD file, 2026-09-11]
variants/slide-in/cad/piku_body.step
54.9 x 63.9 x 32.0 mm

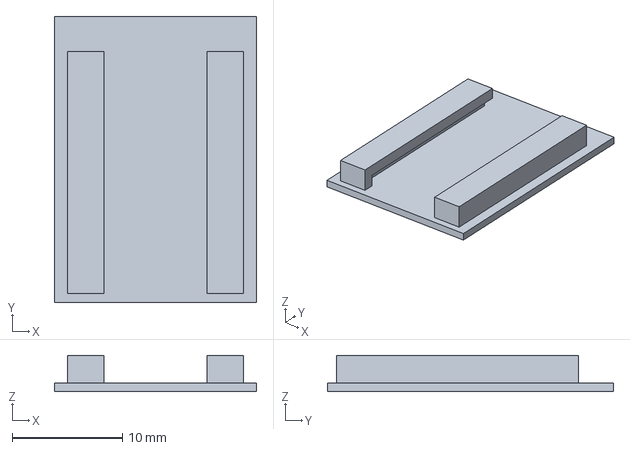
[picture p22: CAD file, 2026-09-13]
variants/cat/cad/cat_touch_fit_test.step
18.4 x 26.0 x 3.30 mm

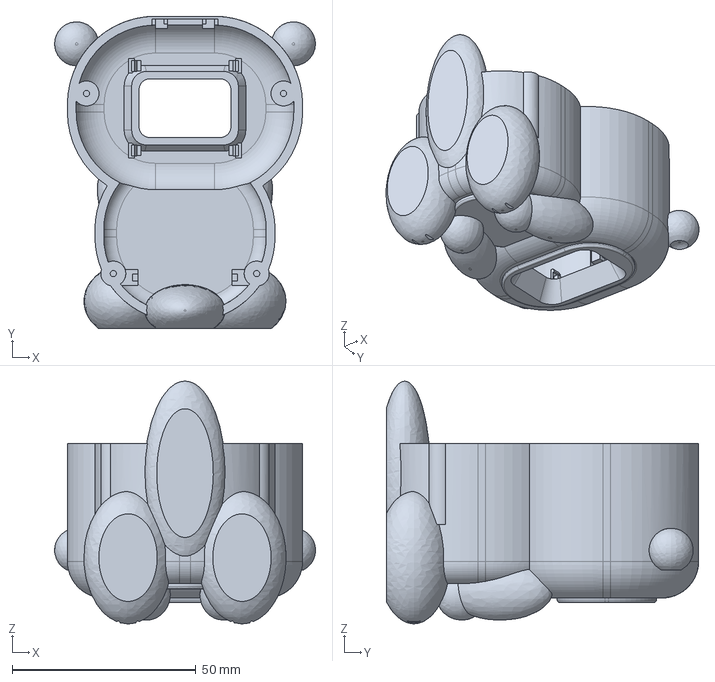
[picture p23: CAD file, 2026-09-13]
variants/otter/cad/otter_body.step
71.0 x 85.0 x 66.0 mm

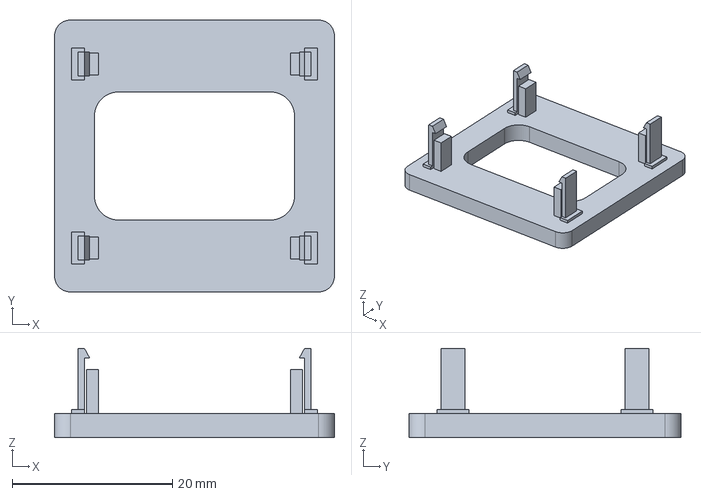
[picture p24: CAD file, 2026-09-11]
variants/slide-in/cad/piku_oled_fit_test.step
35.0 x 34.0 x 11.2 mm

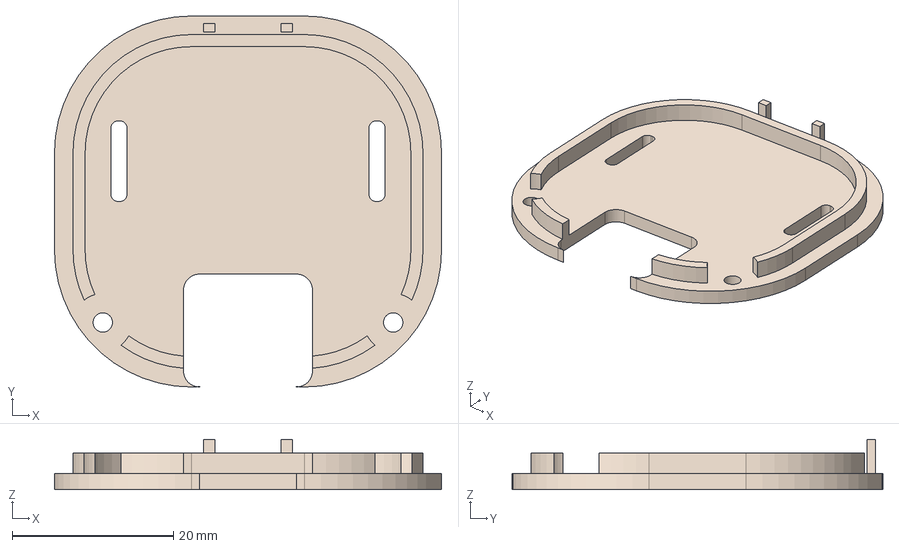
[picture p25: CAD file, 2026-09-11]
variants/slide-in/cad/piku_back.step
48.0 x 46.0 x 6.20 mm

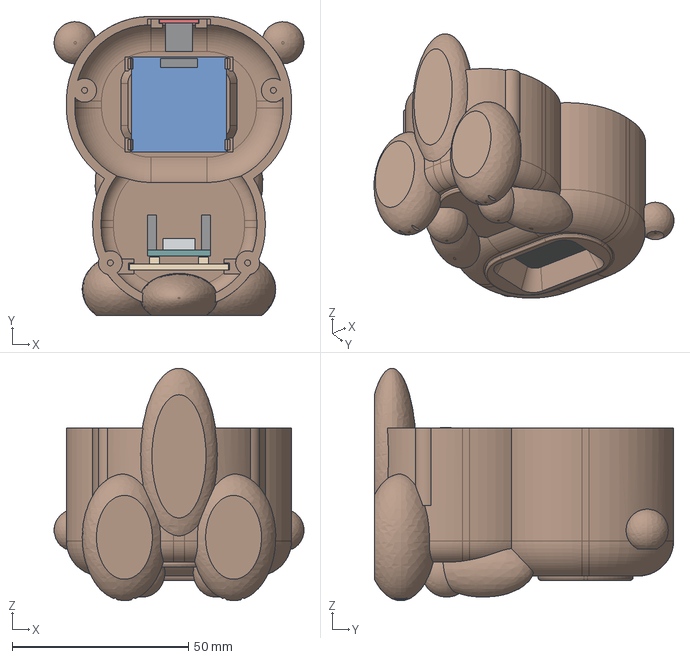
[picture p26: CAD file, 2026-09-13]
variants/otter/cad/otter_inside.step
71.0 x 85.0 x 66.0 mm

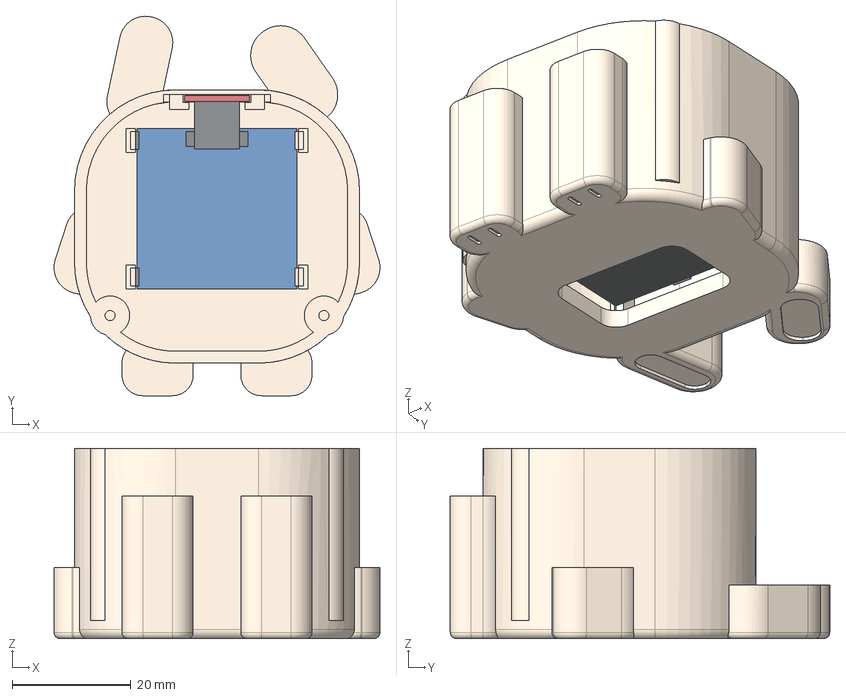
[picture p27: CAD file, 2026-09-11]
variants/slide-in/cad/piku_mount_preview.step
54.9 x 63.9 x 32.0 mm

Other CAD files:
variants/otter/cad/otter_oled_fit_test.step
variants/cat/cad/cat_body_tape.step
variants/cat/cad/cat_back.step
variants/otter/cad/otter_body_tape.step
cad/piku_back.step
cad/piku_back.stl
cad/piku_body.step
cad/piku_body.stl
variants/cat/cad/cat_back.stl
variants/cat/cad/cat_body.stl
variants/cat/cad/cat_body_tape.stl
variants/cat/cad/cat_c3_tray.step
variants/cat/cad/cat_c3_tray.stl
variants/cat/cad/cat_inside.step
variants/cat/cad/cat_oled_fit_test.stl
variants/cat/cad/cat_shell_review.step
variants/cat/cad/cat_touch_fit_test.stl
variants/otter/cad/otter_back.step
variants/otter/cad/otter_back.stl
variants/otter/cad/otter_body.stl
variants/otter/cad/otter_body_tape.stl
variants/otter/cad/otter_oled_fit_test.stl
variants/otter/cad/otter_touch_fit_test.step
variants/slide-in/cad/piku_back.stl
variants/slide-in/cad/piku_body.stl
variants/slide-in/cad/piku_oled_fit_test.stl
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

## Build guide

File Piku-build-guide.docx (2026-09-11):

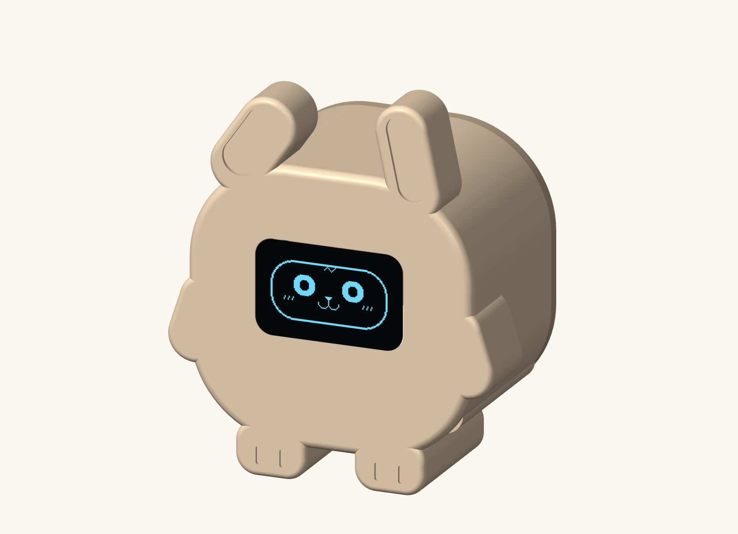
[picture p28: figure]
OpenAI_Photography_2026_04

# Piku desk robot

A tiny bunny desk friend Shopping and build guide | | About 55 mm wide and 64 mm tall September 2026

Meet Piku, a sleepy little bunny with one tilted ear and tiny paws. Its OLED shows a whole face: eyes, nose, mouth and cheeks. Tap for a smile, double-tap for hearts, or hold a touch for a shy wink. Piku naps after a quiet minute.

This guide covers the shopping links, wiring, printing and assembly. You need three small boards, two printed parts and USB power. Piku stays still. The picture is a CAD preview; test the electronics on the table before assembly.

# Buy these little parts

Buy one of each board below. The product names are clickable. Prices are the listings seen on 11 September 2026; confirm tax, delivery and stock at checkout.

Part to buy | Listed INR | Shopping link
ESP32 C3 SuperMini HW 466AB USB C board with soldered headers | 274 | Buy the ESP32 (https://quartzcomponents.com/collections/nodemcu-esp/products/esp32-c3-super-mini-development-board-with-soldered-headers-hw-466ab)
0.96 inch OLED SSD1306 128 by 64 with four I2C pins | 144 | Buy the OLED (https://quartzcomponents.com/products/oled-display-0-96-inch-i2c-interface-4-pin-blue-ssd1306)
TTP223 red touch module 15 by 11 mm PCB with three pins | 30 | Buy the touch sensor (https://www.dnatechindia.com/red-ttp-223-touch-switch-sensor-module-india.html)

The three boards total INR 448. The ESP32 listing had limited stock. If it is unavailable, look for the same ESP32 C3 SuperMini layout; a full-size ESP32 board will not fit this shell.

## Also gather

A USB A to USB C data cable; a 10 cm female-to-female jumper set; a little thin hookup wire; two M2 by 6 mm self-tapping screws; thin double-sided tape; electrical tape; and two small non-slip pads for the feet.

Browse jumper wires (https://quartzcomponents.com/collections/popular-products?page=1&view=boost-pfs-original) | Browse USB cables (https://quartzcomponents.com/collections/communication-cables)

Reuse a known data cable and a normal 5 V USB charger if you have them. Budget about INR 1,000 to 1,500 with self-printed parts and delivery. Tools and outsourced printing cost extra.

## Before ordering

The display must say 0.96 inch, SSD1306, 128 by 64 and four-pin I2C. The linked one has blue pixels; a white version works if its board fits. Avoid seven-pin SPI and 1.3 inch displays. Use the small red touch board; larger blue touch boards do not fit the crown recess.

Borrow a soldering iron, solder, cutters and a small screwdriver. Some modules arrive with loose headers. The shared power wires also need two small soldered joins; the finished build is not completely solder-free.

# Wire it and print the shell

Unplug USB while wiring. Match the printed pin labels, not the order of pins in a photo. Both modules use the ESP32 board’s 3V3 output.

Module | Its pin | ESP32 connection
OLED | VCC or VDD | 3V3
OLED | GND | GND
OLED | SDA | GPIO4
OLED | SCL or SCK | GPIO5
Touch module | VCC | 3V3
Touch module | GND | GND
Touch module | OUT or I/O | GPIO3

Make one short Y-shaped lead from 3V3 to both VCC pins, and another from GND to both ground pins. Solder and insulate each join. Do not squeeze two jumper sockets onto one pin. Nothing connects to the ESP32 5V pin.

## Print two parts

In the ZIP, open cad/piku_body.stl and cad/piku_back.stl in your slicer. Print one of each in PLA at 100% scale using millimetres. Use a 0.4 mm nozzle, 0.2 mm layers, three walls and 15% infill.

The files already lie flat: body face down with its open back upward; lid exterior down with its locating lip upward. Supports should not be needed in these orientations. The shell is about 55 mm wide, 34 mm deep and 64 mm tall, including ears and paws.

Use cream or pastel PLA. Paint the inner ear recesses pink if you like. The thin patch between the ears, toward the back of the crown, is the touch area; leave it unpainted.

Fit check: the OLED board is roughly 27 by 27 mm. Generic boards vary, so measure yours before printing and align the lit screen by hand. The shell deliberately uses tape instead of fixed PCB mounting holes. Its CAD and STL geometry were checked; physical fit has not been tested.

# Bring Piku to life

1 Install Arduino IDE and the esp32 package by Espressif Systems in Boards Manager. If the package is missing, follow the linked installation instructions below.

2 Install Adafruit SSD1306 and Adafruit GFX Library in Library Manager, with their dependencies. Extract the ZIP and open firmware/Piku/Piku.ino. Keep piku_faces.h in that same folder.

3 Select ESP32C3 Dev Module, 4 MB flash, USB CDC On Boot Enabled, and the connected port. Upload with the data cable. If needed, hold BOOT, tap RESET, release BOOT, select the port again and upload.

Arduino IDE (https://www.arduino.cc/en/software/) | ESP32 installation help (https://docs.espressif.com/projects/arduino-esp32/en/latest/installing.html) | USB upload help (https://docs.espressif.com/projects/esp-idf/en/stable/esp32c3/get-started/establish-serial-connection.html)

## Put the boards inside

Test the face and touch sensor on the table first. Keep the touch board in active-high momentary mode: its output should be high only while touched, not latched on after a tap.

Unplug USB. Tape the OLED behind the opening, fixing its PCB edges without pressing on the glass. Place the ESP32 on insulating tape at the bottom, with USB facing the rear opening. Check cable access before securing it.

Attach the touch board’s sensing side snugly beneath the thin crown patch. Use thin tape at its edges and keep an air gap out of the sensing area. Keep loose wires away from it. Insulate exposed joints, tuck in short leads, and close the lid with the two screws. Tighten gently.

Plug in and leave the head untouched for two seconds. Tap for a smile; double-tap for hearts; hold for two seconds for a shy wink. Piku sleeps after 60 seconds and wakes with a surprised face. Piku-face-expressions.png shows all nine frames.

## If something does not work

Blank screen: check 3V3, GND and pins 4 and 5; the sketch tries both 0x3C and 0x3D. Upside down: change setRotation(0) to setRotation(2). Touch stuck on: check momentary mode and move wires away. No USB port: try a data cable and the BOOT sequence.

The starter sketch is source-reviewed but has not been compiled or run on a physical board here. Start with the bench test before sealing the shell. Wi-Fi, an account and a battery are not needed.

Piku desk robot September 2026

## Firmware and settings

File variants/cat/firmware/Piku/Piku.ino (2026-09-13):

/* Piku the sleepy bunny - a tiny touch-reactive desk friend.
   Board: ESP32C3 Dev Module; USB CDC On Boot: Enabled; flash: 4 MB.
   Libraries: Adafruit SSD1306 and Adafruit GFX (install dependencies too).
   Keep piku_faces.h beside this sketch; it contains the full-face artwork.
   OLED: 3V3, GND, SDA GPIO4, SCL GPIO5. TTP223: 3V3, GND, OUT GPIO3.
   TTP223 must use active-high MOMENTARY mode, not toggle mode.
   Source reviewed; not compiled or tested on physical hardware here.
*/
#include <Arduino.h>
#include <Wire.h>
#include <Adafruit_GFX.h>
#include <Adafruit_SSD1306.h>
#include <esp_system.h>
#include "piku_faces.h"

constexpr int SDA_PIN=4,SCL_PIN=5,TOUCH_PIN=3;
constexpr uint32_t SLEEP_AFTER_MS=60000;
Adafruit_SSD1306 face(128,64,&Wire,-1);
uint32_t bootAt=0,lastFrame=0,lastInteraction=0,lastTap=0,emotionStart=0;
uint32_t gazeStart=0,gazeWait=2500,blinkStart=0,blinkWait=3000,rawChanged=0;
bool rawTouch=false,touching=false,seenTap=false,hearts=false;
bool displayReady=false,sensorReady=false,waking=false;
PikuExpression gaze=PIKU_IDLE;

bool i2cPresent(uint8_t address) {
  Wire.beginTransmission(address);
  return Wire.endTransmission()==0;
}

void setup() {
  Serial.begin(115200);
  pinMode(TOUCH_PIN,INPUT_PULLDOWN);
  randomSeed(esp_random());
  Wire.begin(SDA_PIN,SCL_PIN);
  Wire.setTimeOut(30);
  uint8_t address=i2cPresent(0x3C)?0x3C:(i2cPresent(0x3D)?0x3D:0);
  if (!address || !face.begin(SSD1306_SWITCHCAPVCC,address,true,false)) {
    Serial.println("Piku: OLED not found. Check 3V3, GND, SDA=4, SCL=5.");
    return;
  }
  displayReady=true;
  face.clearDisplay();
  face.setRotation(0); // Change to 2 if the display is installed upside down.
  face.ssd1306_command(SSD1306_SETCONTRAST);
  face.ssd1306_command(0x60);
  face.display();
  bootAt=lastInteraction=emotionStart=gazeStart=blinkStart=millis();
  Serial.println("Piku ready. Leave the touch pad alone for two seconds.");
}

void loop() {
  const uint32_t now=millis();
  if (!displayReady) {delay(20);return;}
  if (!sensorReady && now-bootAt>=2000) sensorReady=true;
  const bool sensed=sensorReady && digitalRead(TOUCH_PIN)==HIGH;
  if (sensed!=rawTouch) {rawTouch=sensed;rawChanged=now;}
  if (now-rawChanged>=25 && touching!=rawTouch) {
    touching=rawTouch;
    if (touching) {
      waking=now-lastInteraction>=SLEEP_AFTER_MS;
      hearts=seenTap && now-lastTap<450;
      seenTap=true;
      lastTap=emotionStart=lastInteraction=now;
    } else {
      emotionStart=now; // Keep the smile for a moment after release.
      waking=false;
    }
  }
  if (touching) lastInteraction=now;
  if (now-lastFrame<33) return;
  lastFrame=now;
  if (now-gazeStart>=gazeWait) {
    gazeStart=now;gazeWait=random(2200,6000);
    gaze=static_cast<PikuExpression>(random(0,3));
  }
  if (now-blinkStart>=blinkWait+140) {
    blinkStart=now;blinkWait=random(2200,5200);
  }
  PikuExpression expression=gaze;
  if (now-lastInteraction>=SLEEP_AFTER_MS) expression=PIKU_SLEEP;
  else if (waking && now-emotionStart<300) expression=PIKU_SURPRISED;
  else if (touching && now-lastTap>=2000) expression=PIKU_SHY;
  else if (hearts && (touching || now-emotionStart<1200)) expression=PIKU_LOVE;
  else if (touching || now-emotionStart<1200) expression=PIKU_HAPPY;
  else if (now-blinkStart>=blinkWait) expression=PIKU_BLINK;
  face.clearDisplay();
  face.drawBitmap(0,0,PIKU_FACES[expression],128,64,SSD1306_WHITE);
  face.display();
  delay(1);
}

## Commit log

2026-09-11 Center Piku eyes and make curious gaze directions distinct
    [piku_assembly.step]
2026-09-11 Add optional OLED clips and slide-in touch mount prototype
    [piku_back.step, piku_back.stl, piku_body.step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]
2026-09-13 Add Piku otter as a separate enclosure variant
    [otter_assembly.step, otter_back.step, otter_back.stl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]
2026-09-13 Add refined Piku cat variant with painted OLED preview
    [cat_assembly.step, cat_back.step, cat_back.stl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]
